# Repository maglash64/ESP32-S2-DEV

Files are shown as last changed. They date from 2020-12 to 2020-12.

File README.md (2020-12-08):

# ESP32-S2-DEV
ESP32-S2 Dev Board 
JLCPCB 2313 4-Layer Controlled Impedence Stackup All Components Available on LCSC.  
Features: 
128Mb FLASH. 
USB-C Connector for Programming All Usable GPIOs exposed. 
PCB etched Inverted F Antenna.
Pi Matching required according to choosen PCB stackup.

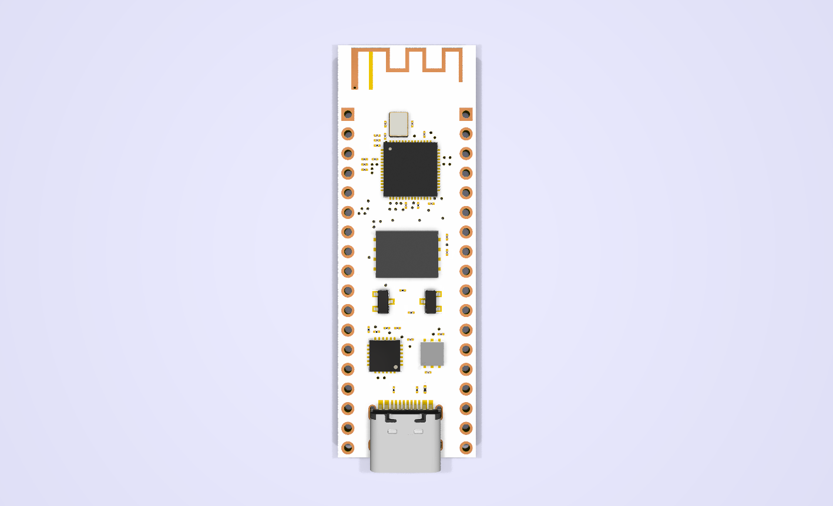
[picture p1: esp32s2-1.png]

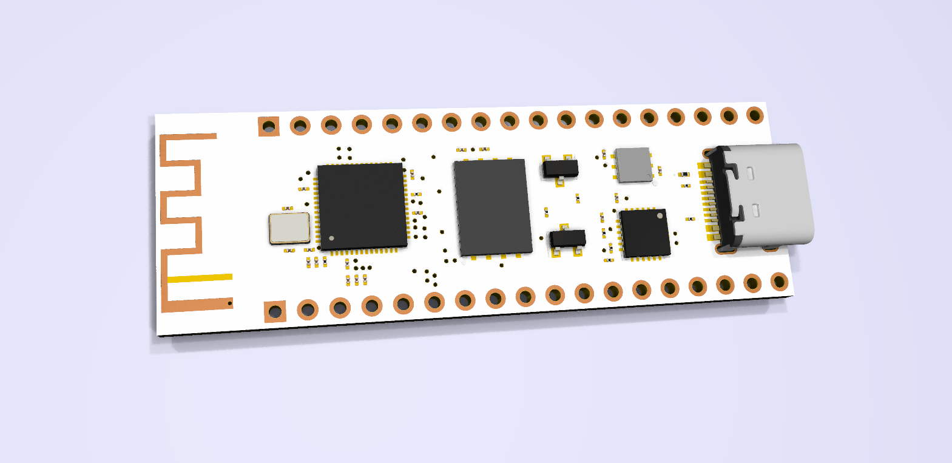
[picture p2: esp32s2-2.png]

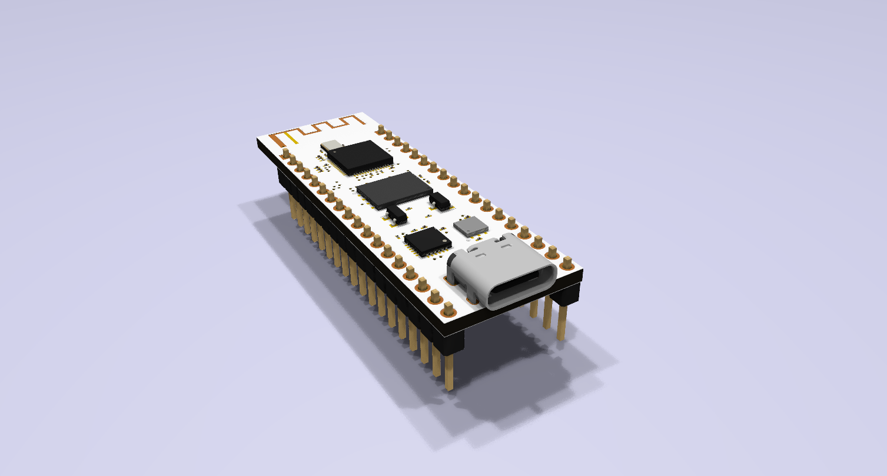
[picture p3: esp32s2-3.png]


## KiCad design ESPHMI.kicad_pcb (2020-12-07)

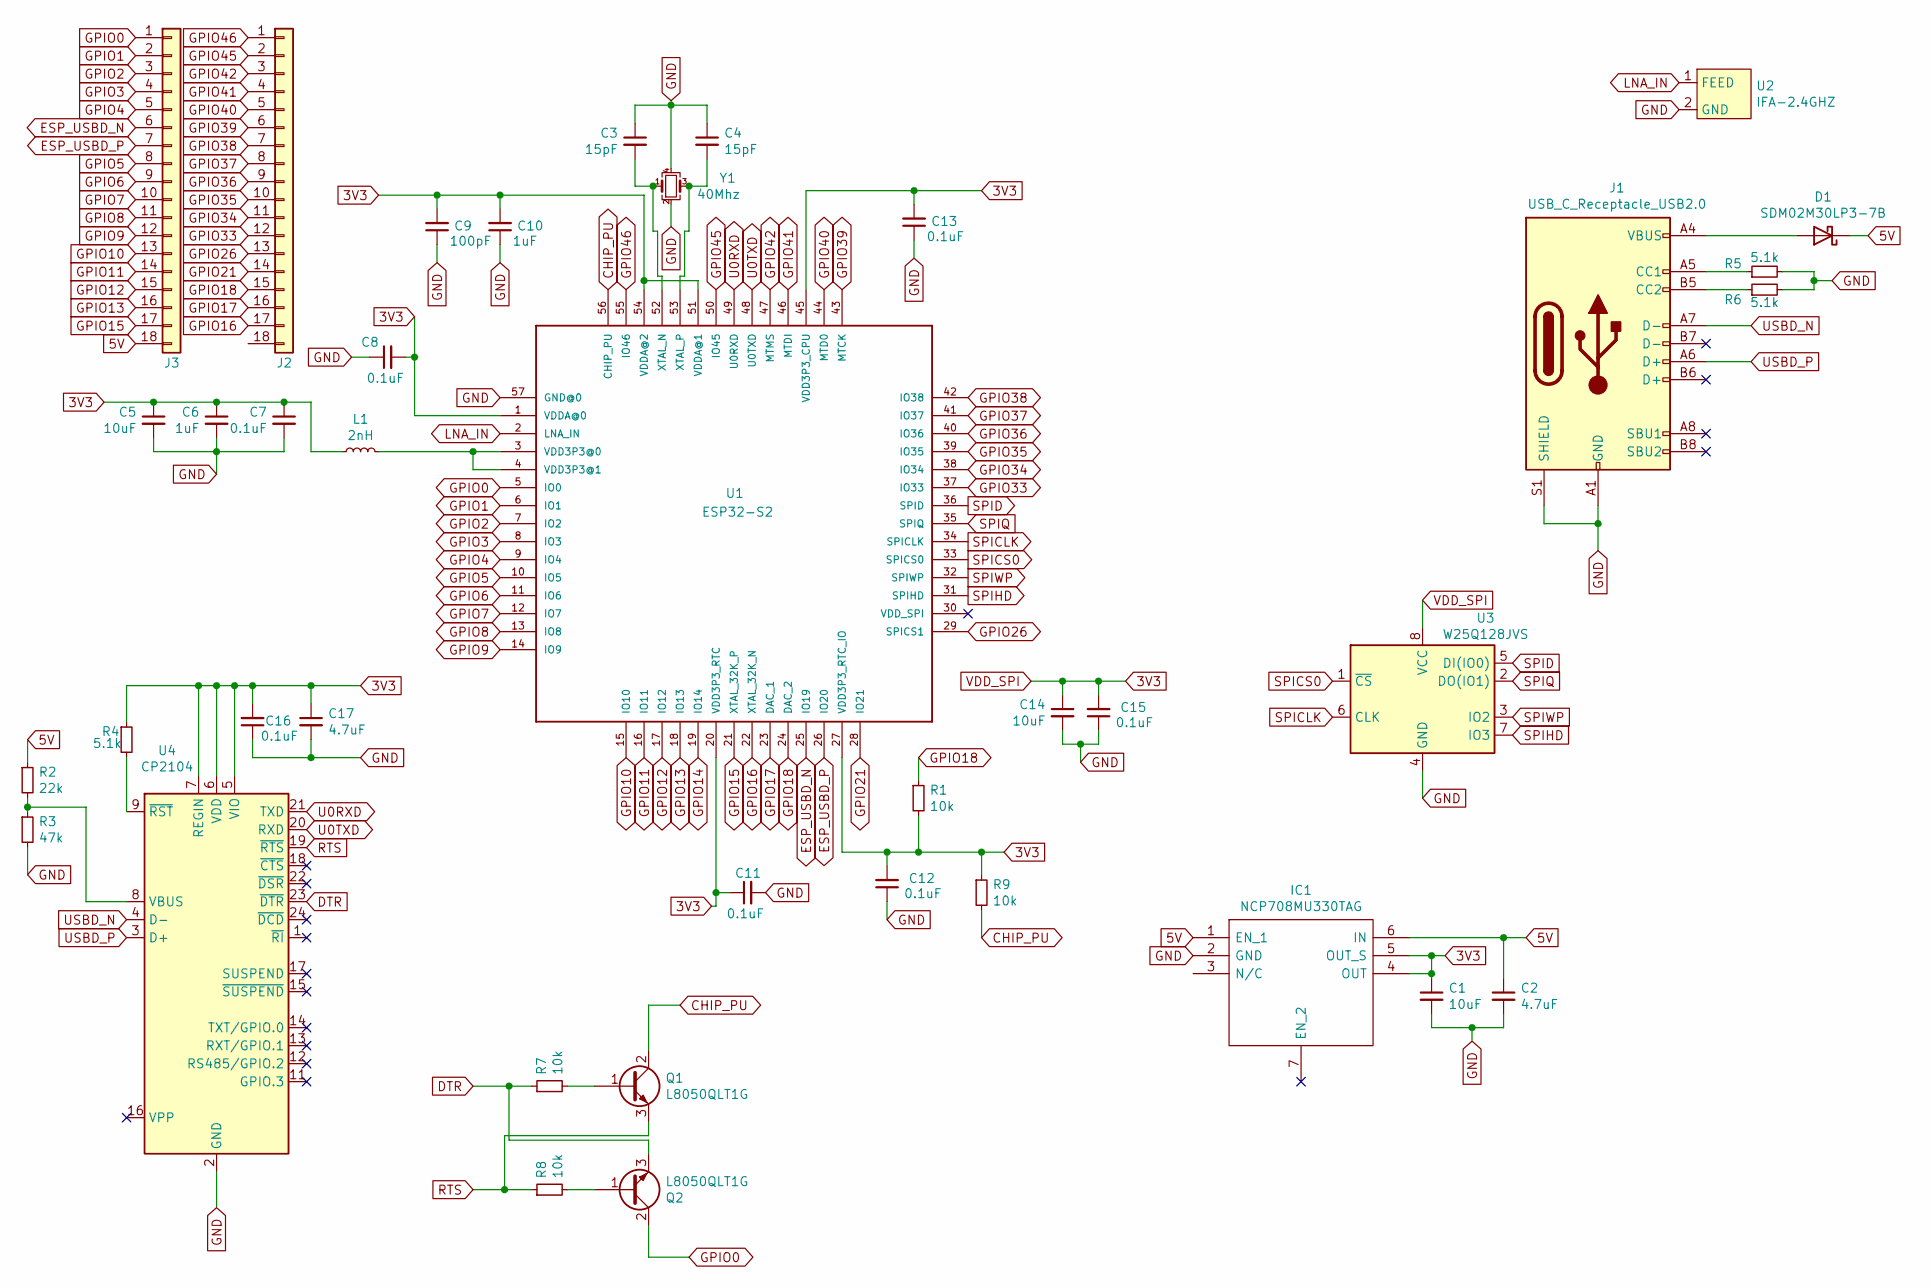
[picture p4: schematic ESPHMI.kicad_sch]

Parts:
C1, C5, C14: 10uF; C_01005_0402Metric
C2, C17: 4.7uF; C_01005_0402Metric
C3, C4: 15pF; C_01005_0402Metric
C6, C10: 1uF; C_01005_0402Metric
C7, C8, C11, C12, C13, C15, C16: 0.1uF; C_01005_0402Metric
C9: 100pF; C_01005_0402Metric
D1: SDM02M30LP3-7B; D_0201_0603Metric
IC1: NCP708MU330TAG; SON95P300X300X55-7N; Mouser Part Number 863-NCP708MU330TAG
J1: USB_C_Receptacle_USB2.0; USB_C_Receptacle_HRO_TYPE-C-31-M-12
J2, J3: Conn_01x18; PinHeader_1x18_P2.54mm_Vertical
L1: 2nH; L_01005_0402Metric
Q1, Q2: L8050QLT1G; SOT-23
R1, R7, R8, R9: 10k; R_01005_0402Metric
R2: 22k; R_01005_0402Metric
R3: 47k; R_01005_0402Metric
R4, R5, R6: 5.1k; R_01005_0402Metric
U1: ESP32-S2; QFN40P700X700X90-57T400N
U2: IFA-2.4GHZ
U3: W25Q128JVS; W25Q128JVEIQ
U4: CP2104; QFN-24-1EP_4x4mm_P0.5mm_EP2.6x2.6mm
Y1: 40Mhz; Crystal_SMD_2520-4Pin_2.5x2.0mm

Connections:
3V3: C1.1, C5.1, C6.1, C7.1, C8.2, C9.2, C10.2, C11.1, C12.2, C13.2, C14.1, C15.2, C16.2, C17.1, IC1.4 (OUT), IC1.5 (OUT_S), L1.1, R1.2, R4.1, R9.1, U1.1 (VDDA@0), U1.20 (VDD3P3_RTC), U1.27 (VDD3P3_RTC_IO), U1.45 (VDD3P3_CPU), U1.51 (VDDA@1), U1.54 (VDDA@2), U3.8 (VCC), U4.5 (VIO), U4.6 (VDD), U4.7 (REGIN)
5V: C2.1, D1.1 (K), IC1.1 (EN_1), IC1.6 (IN), J3.18, R2.1
CHIP_PU: Q1.2 (C), R9.2, U1.56 (CHIP_PU)
DTR: Q2.3 (E), R7.1, U4.23 (~DTR)
ESP_USBD_N: J3.6, U1.25 (IO19)
ESP_USBD_P: J3.7, U1.26 (IO20)
GND: C1.2, C2.2, C3.1, C4.1, C5.2, C6.2, C7.2, C8.1, C9.1, C10.1, C11.2, C12.1, C13.1, C14.2, C15.1, C16.1, C17.2, IC1.2 (GND), J1.A1 (GND), J1.A12 (GND), J1.B1 (GND), J1.B12 (GND), J1.S1 (SHIELD), R3.2, R5.2, R6.2, U1.57 (GND@0), U2.2 (GND), U3.4 (GND), U4.2 (GND), U4.25 (GND), Y1.2, Y1.4
GPIO0: J3.1, Q2.2 (C), U1.5 (IO0)
GPIO1: J3.2, U1.6 (IO1)
GPIO2: J3.3, U1.7 (IO2)
GPIO3: J3.4, U1.8 (IO3)
GPIO4: J3.5, U1.9 (IO4)
GPIO5: J3.8, U1.10 (IO5)
GPIO6: J3.9, U1.11 (IO6)
GPIO7: J3.10, U1.12 (IO7)
GPIO8: J3.11, U1.13 (IO8)
GPIO9: J3.12, U1.14 (IO9)
GPIO10: J3.13, U1.15 (IO10)
GPIO11: J3.14, U1.16 (IO11)
GPIO12: J3.15, U1.17 (IO12)
GPIO13: J3.16, U1.18 (IO13)
GPIO14: U1.19 (IO14)
GPIO15: J3.17, U1.21 (XTAL_32K_P)
GPIO16: J2.17, U1.22 (XTAL_32K_N)
GPIO17: J2.16, U1.23 (DAC_1)
GPIO18: J2.15, R1.1, U1.24 (DAC_2)
GPIO21: J2.14, U1.28 (IO21)
GPIO26: J2.13, U1.29 (SPICS1)
GPIO33: J2.12, U1.37 (IO33)
GPIO34: J2.11, U1.38 (IO34)
GPIO35: J2.10, U1.39 (IO35)
GPIO36: J2.9, U1.40 (IO36)
GPIO37: J2.8, U1.41 (IO37)
GPIO38: J2.7, U1.42 (IO38)
GPIO39: J2.6, U1.43 (MTCK)
GPIO40: J2.5, U1.44 (MTD0)
GPIO41: J2.4, U1.46 (MTDI)
GPIO42: J2.3, U1.47 (MTMS)
GPIO45: J2.2, U1.50 (IO45)
GPIO46: J2.1, U1.55 (IO46)
LNA_IN: U1.2 (LNA_IN), U2.1 (FEED)
unnamed: C3.2, U1.52 (XTAL_N), Y1.1
unnamed: C4.2, U1.53 (XTAL_P), Y1.3
unnamed: D1.2 (A), J1.A4 (VBUS), J1.A9 (VBUS), J1.B4 (VBUS), J1.B9 (VBUS)
unnamed: J1.A5 (CC1), R5.1
unnamed: J1.B5 (CC2), R6.1
unnamed: L1.2, U1.3 (VDD3P3@0), U1.4 (VDD3P3@1)
unnamed: Q1.1 (B), R7.2
unnamed: Q2.1 (B), R8.2
unnamed: R2.2, R3.1, U4.8 (VBUS)
unnamed: R4.2, U4.9 (~RST)
RTS: Q1.3 (E), R8.1, U4.19 (~RTS)
SPICLK: U1.34 (SPICLK), U3.6 (CLK)
SPICS0: U1.33 (SPICS0), U3.1 (~CS)
SPID: U1.36 (SPID), U3.5 (DI(IO0))
SPIHD: U1.31 (SPIHD), U3.7 (IO3)
SPIQ: U1.35 (SPIQ), U3.2 (DO(IO1))
SPIWP: U1.32 (SPIWP), U3.3 (IO2)
U0RXD: U1.49 (U0RXD), U4.21 (TXD)
U0TXD: U1.48 (U0TXD), U4.20 (RXD)
USBD_N: J1.A7 (D-), U4.4 (D-)
USBD_P: J1.A6 (D+), U4.3 (D+)

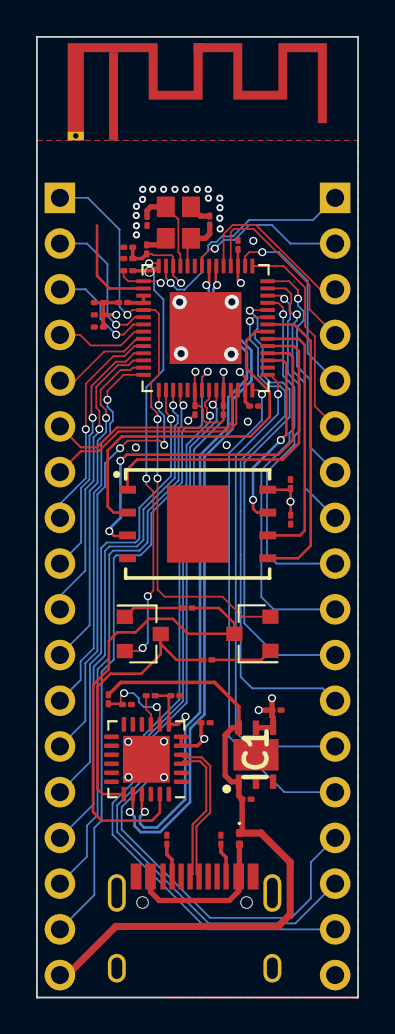
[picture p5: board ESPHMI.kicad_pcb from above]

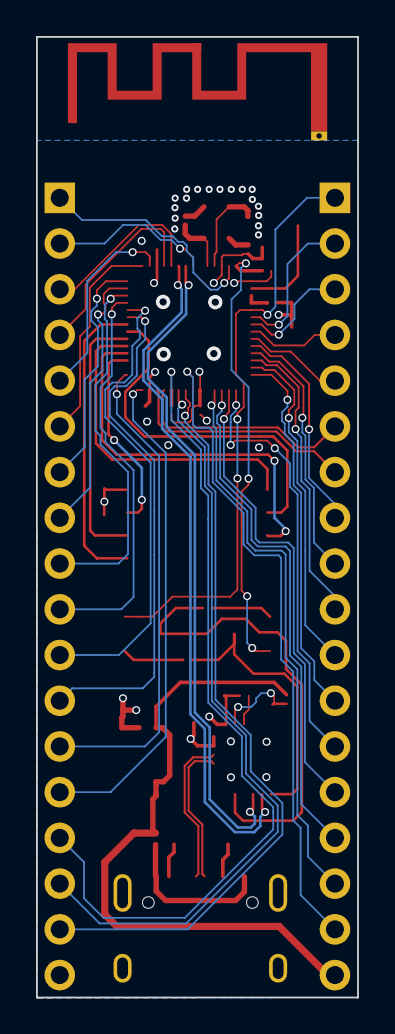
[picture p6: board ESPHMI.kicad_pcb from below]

Board: 4 copper layers, 17.8 x 53.4 mm, 39 parts (2 on the bottom side), 61 nets.
